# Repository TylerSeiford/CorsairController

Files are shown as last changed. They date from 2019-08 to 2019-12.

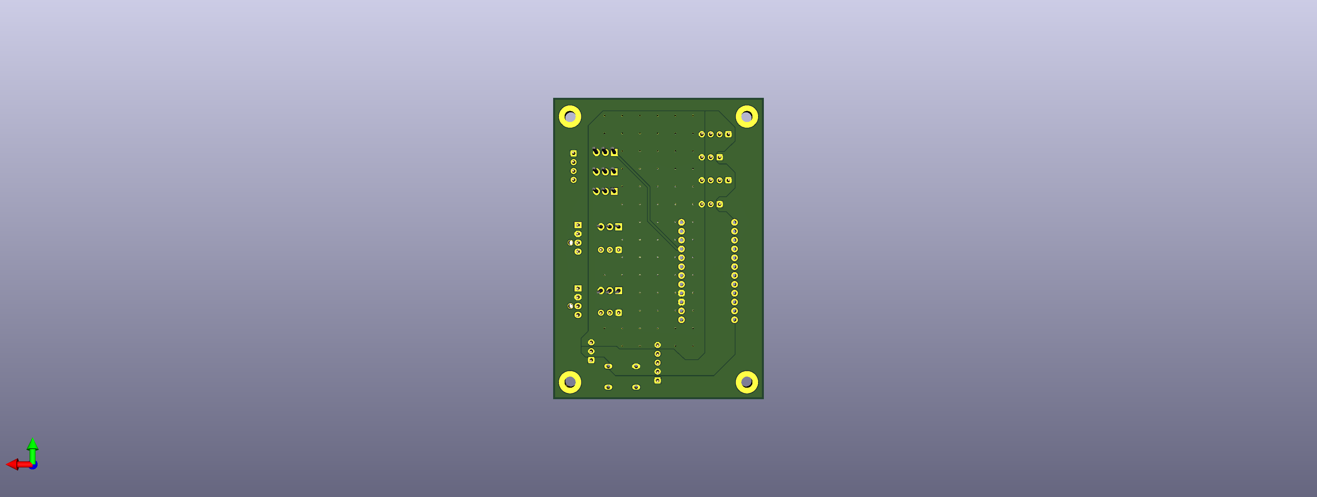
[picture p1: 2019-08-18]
Kicad/Pictures/Back.png

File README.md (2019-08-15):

# CorsairArduinoController
This is the code for my knock off Corsair CommanderPRO using an ATmega32u4 based arduinno.

## Hardware
This uses an arduino pro micro (ATmega32u4) based microcontroller to control addressable and non addressable LED strips.  It utilizes the [CorsairLightingProtocol](https://github.com/Legion2/CorsairLightingProtocol) and builds on top of it to add additional functionality.

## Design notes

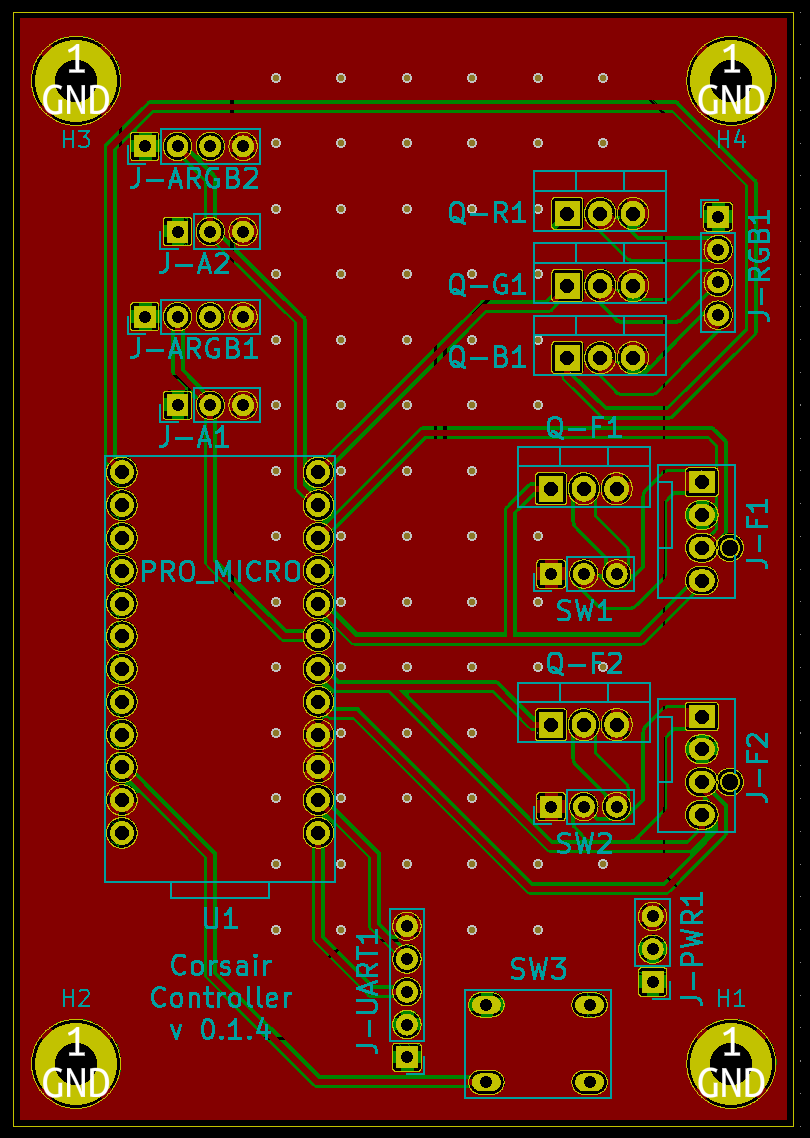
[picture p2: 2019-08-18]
Kicad/Pictures/PCB.png

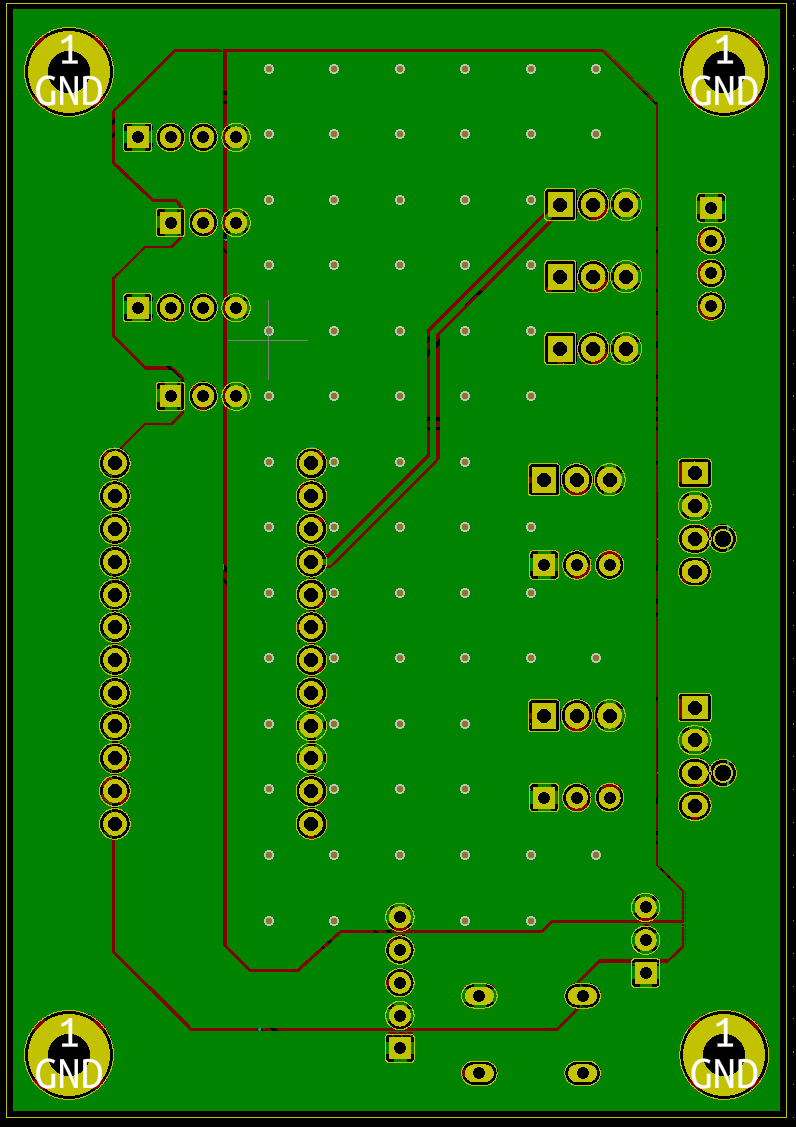
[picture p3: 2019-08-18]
Kicad/Pictures/PCB back.png

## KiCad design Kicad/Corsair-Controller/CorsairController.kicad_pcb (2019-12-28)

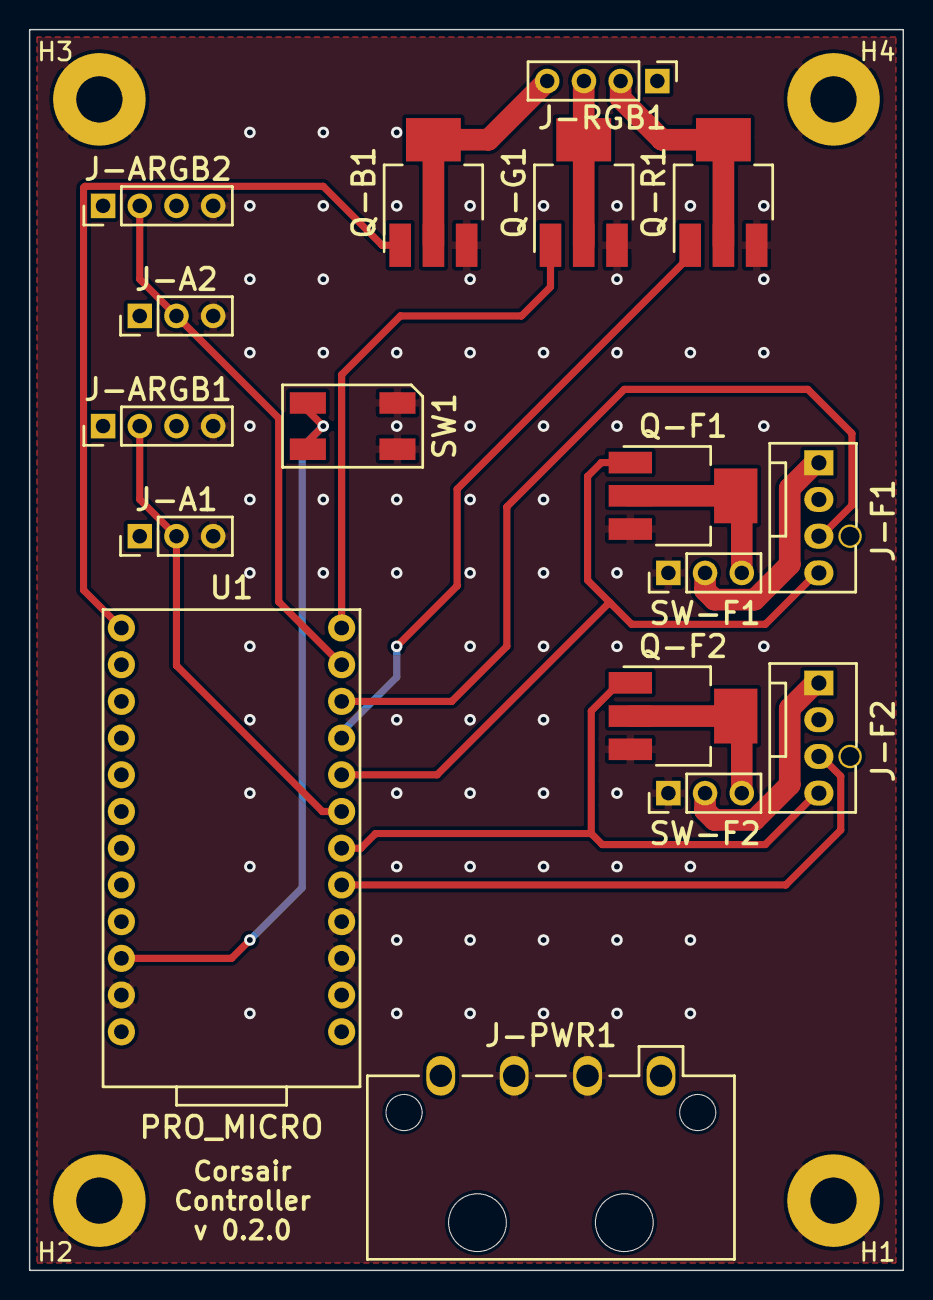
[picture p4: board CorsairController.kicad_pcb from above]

Board: 2 copper layers, 60.5 x 85.9 mm, 21 parts (0 on the bottom side), 20 nets.

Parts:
H1, H2, H3, H4: MountingHole; MountingHole_3.2mm_M3_Pad
J-A1, J-A2: Conn_01x03_Male; PinHeader_1x03_P2.54mm_Vertical
J-ARGB1, J-ARGB2: Conn_01x04_Male; PinHeader_1x04_P2.54mm_Vertical
J-F1, J-F2: Conn_01x04_Male; 0470531000
J-PWR1: Conn_01x04_Female; 641737-1
J-RGB1: Conn_01x04_Male; PinHeader_1x04_P2.54mm_Vertical
Q-B1: Q_NMOS_GDSD; SOT-223
Q-F1, Q-F2: Q_NMOS_GDSD; SOT-223
Q-G1: Q_NMOS_GDSD; SOT-223
Q-R1: Q_NMOS_GDSD; SOT-223
SW1: RESET_SWITCH; PTS_647_SM38_SMTR2_LFS
SW-F1, SW-F2: SW_SPDT; PinHeader_1x03_P2.54mm_Vertical
U1: PRO_MICRO; SPARKFUN_PRO_MICRO

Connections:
/5V: J-ARGB1.1, J-ARGB2.1, J-PWR1.4
/12V: J-A1.1, J-A2.1, J-F1.2, J-F2.2, J-PWR1.1, J-RGB1.1
/A1: J-A1.2, J-ARGB1.2, U1.7
/A2: J-A2.2, J-ARGB2.2, U1.11
/B-5V: Q-B1.1, U1.13
/B-12V: J-RGB1.4, Q-B1.2, Q-B1.4
/F1-5V: J-F1.4, Q-F1.1, U1.8
/F1-12V: Q-F1.2, Q-F1.4, SW-F1.3
/F1-GND: J-F1.1, SW-F1.2
/F1-T: J-F1.3, U1.10
/F2-5V: J-F2.4, Q-F2.1, U1.6
/F2-12V: Q-F2.2, Q-F2.4, SW-F2.3
/F2-GND: J-F2.1, SW-F2.2
/F2-T: J-F2.3, U1.5
/G-5V: Q-G1.1, U1.12
/G-12V: J-RGB1.3, Q-G1.2, Q-G1.4
/R-5V: Q-R1.1, U1.9
/R-12V: J-RGB1.2, Q-R1.2, Q-R1.4
/RESET: SW1.2, SW1.4, U1.22
GND: H1.1, H2.1, H3.1, H4.1, J-A1.3, J-A2.3, J-ARGB1.4, J-ARGB2.4, J-PWR1.2, J-PWR1.3, Q-B1.3, Q-F1.3, Q-F2.3, Q-G1.3, Q-R1.3, SW1.1, SW1.3, SW-F1.1, SW-F2.1, U1.3, U1.4, U1.23

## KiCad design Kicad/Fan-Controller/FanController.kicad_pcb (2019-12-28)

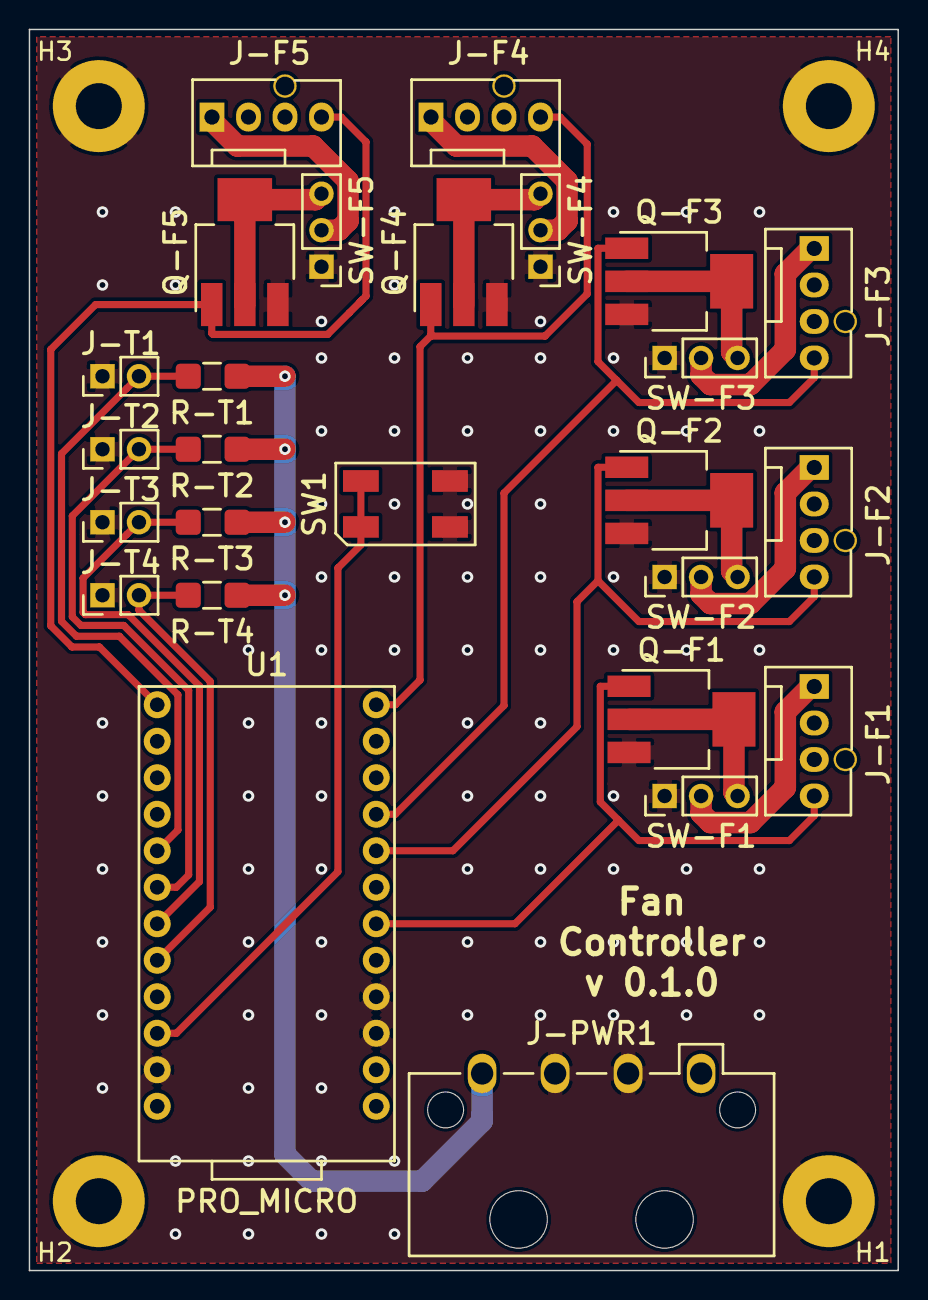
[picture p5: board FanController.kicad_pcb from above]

Board: 2 copper layers, 60.5 x 86.4 mm, 30 parts (0 on the bottom side), 23 nets.

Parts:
H1, H2, H3, H4: MountingHole; MountingHole_3.2mm_M3_Pad
J-F1, J-F2, J-F3, J-F4, J-F5: Conn_01x04_Male; 0470531000
J-PWR1: Conn_01x04_Female; 641737-1
J-T1, J-T2, J-T3, J-T4: Conn_01x02_Male; PinHeader_1x02_P2.54mm_Vertical
Q-F1, Q-F2, Q-F3, Q-F4, Q-F5: Q_NMOS_GDSD; SOT-223
R-T1, R-T2, R-T3, R-T4: R; R_1206_3216Metric_Pad1.42x1.75mm_HandSolder
SW1: RESET_SWITCH; PTS_647_SM38_SMTR2_LFS
SW-F1, SW-F2, SW-F3, SW-F4, SW-F5: SW_SPDT; PinHeader_1x03_P2.54mm_Vertical
U1: PRO_MICRO; SPARKFUN_PRO_MICRO

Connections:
/5V: J-PWR1.4, R-T1.2, R-T2.2, R-T3.2, R-T4.2
/12V: J-F1.2, J-F2.2, J-F3.2, J-F4.2, J-F5.2, J-PWR1.1
/F1-5V: J-F1.4, Q-F1.1, U1.6
/F1-12V: Q-F1.2, Q-F1.4, SW-F1.3
/F1-GND: J-F1.1, SW-F1.2
/F2-5V: J-F2.4, Q-F2.1, U1.8
/F2-12V: Q-F2.2, Q-F2.4, SW-F2.3
/F2-GND: J-F2.1, SW-F2.2
/F3-5V: J-F3.4, Q-F3.1, U1.9
/F3-12V: Q-F3.2, Q-F3.4, SW-F3.3
/F3-GND: J-F3.1, SW-F3.2
/F4-5V: J-F4.4, Q-F4.1, U1.12
/F4-12V: Q-F4.2, Q-F4.4, SW-F4.3
/F4-GND: J-F4.1, SW-F4.2
/F5-5V: J-F5.4, Q-F5.1, U1.13
/F5-12V: Q-F5.2, Q-F5.4, SW-F5.3
/F5-GND: J-F5.1, SW-F5.2
/RESET: SW1.1, SW1.3, U1.22
/T1: J-T1.2, R-T1.1, U1.17
/T2: J-T2.2, R-T2.1, U1.18
/T3: J-T3.2, R-T3.1, U1.19
/T4: J-T4.2, R-T4.1, U1.20
GND: H1.1, H2.1, H3.1, H4.1, J-PWR1.2, J-PWR1.3, J-T1.1, J-T2.1, J-T3.1, J-T4.1, Q-F1.3, Q-F2.3, Q-F3.3, Q-F4.3, Q-F5.3, SW1.2, SW1.4, SW-F1.1, SW-F2.1, SW-F3.1, SW-F4.1, SW-F5.1, U1.3, U1.4, U1.23

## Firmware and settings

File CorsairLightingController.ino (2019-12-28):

#include "CommanderPro.h"
#include "Config.h"

//Hardware pin definitions
constexpr uint8_t FAN_1_PWM = 5;
constexpr uint8_t FAN_1_TACH = 7;

constexpr uint8_t FAN_2_PWM = 3;
constexpr uint8_t FAN_2_TACH = 2;

constexpr uint8_t CHANNEL_1 = 4;
constexpr uint8_t CHANNEL_2 = 8;

constexpr uint8_t RGB_1 = 6;
constexpr uint8_t RGB_2 = 9;
constexpr uint8_t RGB_3 = 10;


CommanderPro<LEDS_PER_CHANNEL>* cp;

void setup() {
	disableBuildInLEDs();

	cp = new CommanderPro<LEDS_PER_CHANNEL>(true);

	FastLED.addLeds<LED_CHIPSET_1, CHANNEL_1, LED_ORDER_1>(cp->channel1, LEDS_PER_CHANNEL);
	FastLED.addLeds<LED_CHIPSET_2, CHANNEL_2, LED_ORDER_2>(cp->channel2, LEDS_PER_CHANNEL);

	pinMode(RGB_1, OUTPUT);
	pinMode(RGB_2, OUTPUT);
	pinMode(RGB_3, OUTPUT);

	cp->addFan(0, new PWMFan(FAN_1_PWM, F1_MIN, F1_MAX));
	cp->addFan(1, new PWMFan(FAN_2_PWM, F2_MIN, F2_MAX));
}

void loop() {
	if (cp->update()) {
		FastLED.show();

		analogWrite(RED_PIN, cp->channel1->r);
		analogWrite(GREEN_PIN, cp->channel1->g);
		analogWrite(BLUE_PIN, cp->channel1->b);
	}
	else {
		delay(3);
	}
}

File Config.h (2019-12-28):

#pragma once

//ARGB setup
constexpr uint8_t LEDS_PER_CHANNEL = 20;
	//Number of LEDs per ARGB channel
#define LED_CHIPSET_1 WS2812B
	//Chipset for ARGB1 header
#define LED_ORDER_1 GRB
	//LED order for ARGB1 header
#define LED_CHIPSET_2 WS2812B
	//Chipset for ARGB2 header
#define LED_ORDER_2 GRB
	//LED order for ARGB2 header


//RGB setup
#define GRB_
	//Order of RGB header


//Fan setup
constexpr uint8_t F1_MIN = 0;
constexpr uint8_t F1_MAX = 950;
	//Min & Max RPMs for Fan1
constexpr uint8_t F2_MIN = 0;
constexpr uint8_t F2_MAX = 1500;
	//Min & Max RPMs for Fan2




// *** FANCY MAGICS FOR RGB SETUP ***
#ifdef RGB_
	#define RED_PIN RGB_1
	#define GREEN_PIN RGB_2
	#define BLUE_PIN RGB_3
#endif
#ifdef RBG_
	#define RED_PIN RGB_1
	#define GREEN_PIN RGB_3
	#define BLUE_PIN RGB_2
#endif
#ifdef GRB_
	#define RED_PIN RGB_2
	#define GREEN_PIN RGB_1
	#define BLUE_PIN RGB_3
#endif
#ifdef GBR_
	#define RED_PIN RGB_3
	#define GREEN_PIN RGB_1
	#define BLUE_PIN RGB_2
#endif
#ifdef BGR_
	#define RED_PIN RGB_3
	#define GREEN_PIN RGB_2
	#define BLUE_PIN RGB_1
#endif
#ifdef BRG_
	#define RED_PIN RGB_2
	#define GREEN_PIN RGB_3
	#define BLUE_PIN RGB_1
#endif

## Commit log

2019-06-08 Added fritzing files
    [LightingController.fzz]
2019-06-11 Wiring update
2019-08-15 Creating fake temperature controller
2019-08-15 PWM fan
2019-08-15 Simple fan controller
2019-08-15 Fan interface update
2019-08-15 Add fan control to commander pro
2019-08-15 Fix board.txt to commander pro IDs
2019-08-15 Working fan control
2019-08-15 Switch to a template system
2019-08-15 Create DC fan
2019-08-15 Updated wiring to dual controller layout
    The second controller is unneeded at the moment but may become useful for full fan control
    [CorsairController.fzz, LightingController.fzz]
2019-08-15 Switching to eagle
    [Master.brd, Master.sch]
2019-08-15 Added schematic and board images
    [Master.brd]
2019-08-15 Pin changes, fixing template issues, added switches for 3 or 4 pin mode
    [Master.brd, Master.sch]
2019-08-15 Last eagle revision & updated readme
    [CorsairController.fzz]
2019-08-15 Removed eagle & fritzing, updated gitignore for KiCad
    [CorsairController.fzz, Master.brd, Master.sch]
2019-08-15 PCB v0.1.0
    Initial kicad upload. This PCB has been a WIP for a while and this is the first time I've uploaded it to github.
    [CorsairController.kicad_pcb, CorsairController.sch]
2019-08-15 PCB v0.1.1
    [CorsairController.kicad_pcb, CorsairController.sch]
2019-08-15 PCB v0.1.2
    [CorsairController.kicad_pcb]
2019-08-15 PCB v0.1.3
    Fixes fan header pinouts
    [CorsairController.kicad_pcb, CorsairController.sch]
2019-08-15 Redo PCB layout to be more efficient.
    [CorsairController.kicad_pcb]
2019-08-15 PCB v0.1.4
    Upload gerbers of first production run!
    [CorsairController-B_Cu.gbr, CorsairController-B_Mask.gbr, CorsairController-B_SilkS.gbr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]
2019-08-18 Small updates & added photos
    [CorsairController.kicad_pcb, CorsairController.sch]
2019-08-23 PCB v0.1.5
    [CorsairController.kicad_pcb, CorsairController.sch]
2019-08-24 Starts of full fan control module
    [CorsairController.sch]
2019-08-24 Fan board is partially complete
    [CorsairController.kicad_pcb, CorsairController.sch]
2019-08-25 PCB v0.1.6
    Next step will be a complete reorganization of the PCB
    [CorsairController.kicad_pcb, CorsairController.sch]
2019-08-25 PCB v0.1.7
    [CorsairController.kicad_pcb, CorsairController.sch]
2019-08-25 Adding SOT-223 footprint from master
2019-08-25 Fan controller v0.0.2
    [CorsairController.kicad_pcb, CorsairController.sch]
2019-08-25 Fan PCB v0.0.3
    [CorsairController.kicad_pcb, CorsairController.sch]
2019-08-27 Fan PCB v0.0.4
    Switched to a molex screw terminal input
    [CorsairController.kicad_pcb, CorsairController.sch]
2019-08-27 PCB v0.1.8
    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
    [CorsairController.kicad_pcb, CorsairController.sch]
2019-08-27 Moved files
    [CorsairController.kicad_pcb, CorsairController.sch]
2019-08-27 Added molex power input
2019-08-27 Fan PCB v0.0.5
    [CorsairController.kicad_pcb]
2019-08-27 PCB v0.1.9
    [CorsairController.kicad_pcb]
2019-08-27 PCB v0.1.9 (reupload)
    [CorsairController.kicad_pcb]
2019-08-27 Fan PCB v0.0.6
    [CorsairController.kicad_pcb]
2019-08-28 PCB v0.1.10
    [CorsairController.kicad_pcb, CorsairController.sch]
2019-08-29 Added reset button footprint & symbol
2019-08-29 PCB v0.1.11
    [CorsairController.kicad_pcb, CorsairController.sch]
2019-08-29 Fan PCB v0.0.7
    [CorsairController.kicad_pcb, CorsairController.sch]
2019-08-29 Renaming footprints
2019-08-29 Updated main PCB with new footprint names
    [CorsairController.kicad_pcb, CorsairController.sch]
2019-08-29 Rename and update fan PCB
    [FanController.kicad_pcb, FanController.sch]
2019-08-31 Switch to WS2112B strips
2019-08-31 Fix footprint to be 3"x2"
    [CorsairController.kicad_pcb]
2019-10-01 Small updates
    [CorsairController.kicad_pcb, FanController.sch]
2019-10-18 Change resistors to 1206 from 0805
    Fan control v0.0.8
    [FanController.kicad_pcb]
2019-11-09 Controller rev 0.2.0
    [CorsairController.kicad_pcb]
2019-11-09 Remove gerbers
    [CorsairController-B_Cu.gbr, CorsairController-B_Mask.gbr, CorsairController-B_SilkS.gbr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]
2019-11-09 FanController rev 0.1.0
    [FanController.kicad_pcb]
